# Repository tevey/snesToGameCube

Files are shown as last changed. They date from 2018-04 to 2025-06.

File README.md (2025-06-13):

# SNES to GameCube adapter

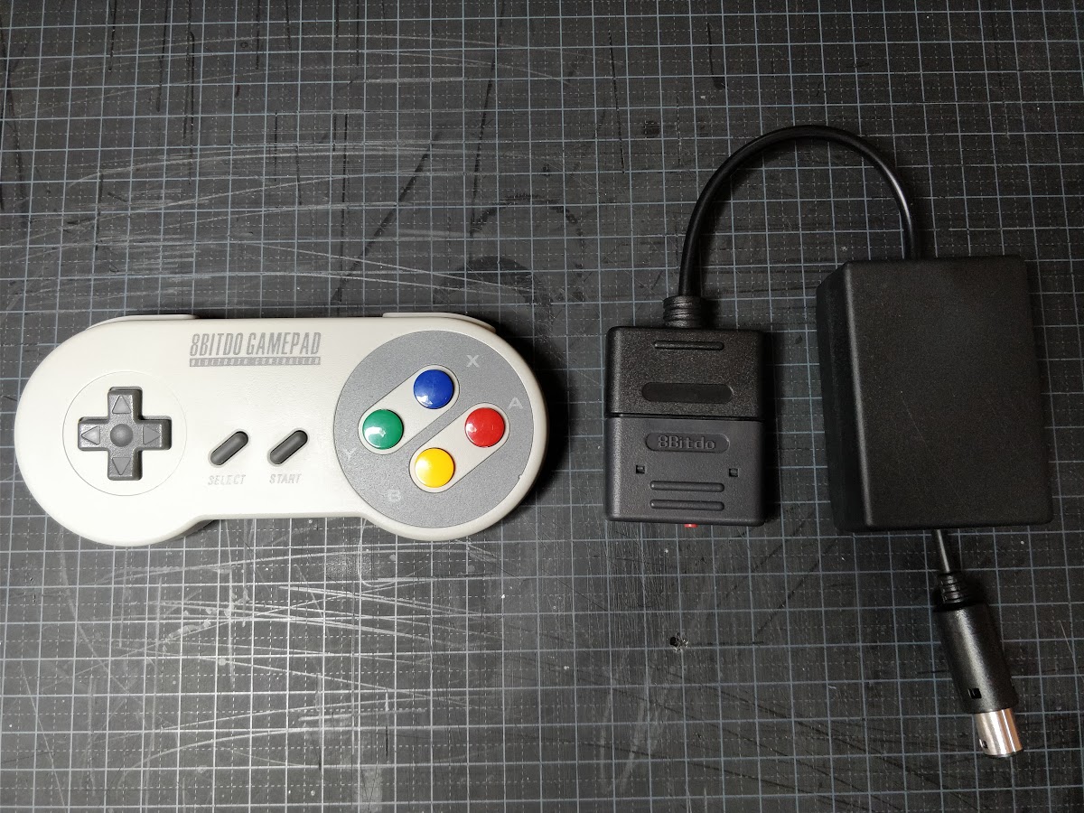
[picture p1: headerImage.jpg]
Image of adapter

Code for building a SNES to GameCube controller adapter.
Also works with the 8Bitdo [Retro Receiver](http://www.8bitdo.com/retro-receiver-snes/)

## Button Mapping

| SNES Button | GameCube Mapping | Notes |
| --- | --- | --- |
| A | A |
| B | B |
| X | X |
| Y | Y |
| Select | Y | Like SNES Hori-pad / for GBA games |
| Start | Start |
| L | L (digital), L (analog: 0/255) | Analog: 255 if pressed, 0 if not |
| R | R (digital), R (analog: 0/255) | Analog: 255 if pressed, 0 if not |
| L+R+Select  | Z |
| D-Pad Left  | D-Pad Left |
| D-Pad Up | D-Pad Up |
| D-Pad Right | D-Pad Right |
| D-Pad Down  | D-Pad Down |

## Software Requirements

- [Arduino IDE](https://www.arduino.cc/en/Main/Software) (tested on 2.3.6)
- [Arduino Nintendo Library](https://github.com/NicoHood/Nintendo) by NicoHood (tested on 1.4.0)

## Hardware

### Parts

- Logic Level Converter 5v <-> 3.3v
- Arduino Pro Mini (5v 16MHz)
- USB -> Serial adapter if your Arduino comes without USB.
- 1kΩ Resistor
- Female SNES controller port (SNES extension cable)
- Male GameCube controller connector (GameCube extension cable)

### Wiring

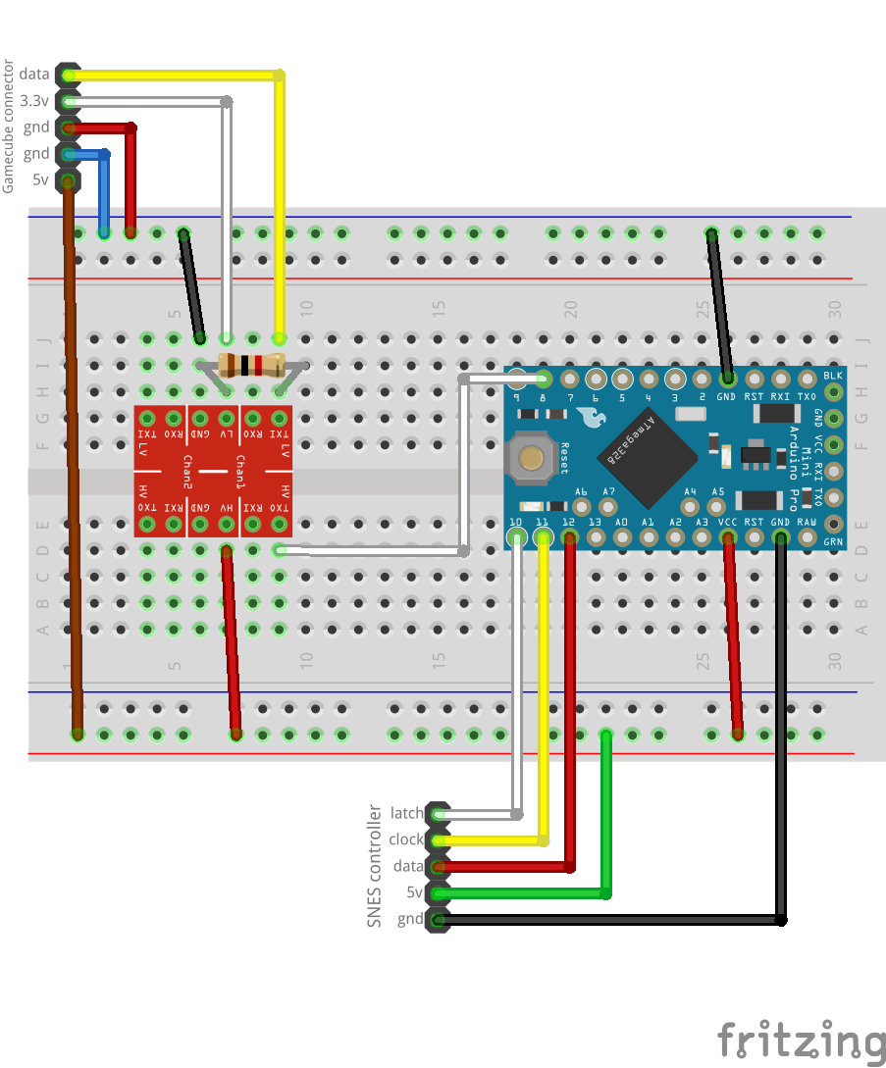
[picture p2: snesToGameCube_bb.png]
Wiring diagram


The colors of the wires in the cables may not match between the original controller and the extension cable, below is the mapping for my cables the colors may be different for you.

#### SNES pinout

| Type  | Original Controller | Extension Cable |
| ----- | --- | --- |
| 5v | white | green |
| clock | yellow | yellow |
| latch | orange | white |
| data  | red | red |
| gnd | brown | black |

#### GameCube Pinout

| Type | Original Controller | Extension Cable |
| ---- | --- | --- |
| gnd  | Black | blue |
| gnd  | white | red |
| gnd  | green | blue |
| data | red | yellow |
| 5v | yellow | brown |
| 3.3v | blue | white |

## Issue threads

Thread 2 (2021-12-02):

Adapter not registering inputs fast enough

MasterJhimmy, 2021-12-02:
Testing this adapter on my Wii I noticed that everything was working alright, but there was a delay. It was very noticeable in fighting games, the adapter would not recognize double taps to run or back off. The problem is that your "write_GC" function is inside of the "if statement" to retrieve data from the SNES controller. Putting the "write_GC" inside the main arduino "loop" mitigate the problem and now everything is working flawless.

Trev154n, 2022-05-04:
@MasterJhimmy can you give me the code you modified? I also noticed a lag using the Wii. thanks.

Trev154n, 2022-05-04:
@MasterJhimmy can you give me the code you modified? I also noticed a lag using the Wii. thanks.

MasterJhimmy, 2022-05-04:
@Trev154n Sure. I've added some features, like when you press the L or R button it registers not only the digital signal, but also the full press of the analog button. Here it is:
[snesToGameCube.txt](https://github.com/tevey/snesToGameCube/files/8627765/snesToGameCube.txt)

Trev154n, 2022-05-04:
@MasterJhimmy thank you very much Bro, I tested it here it's wonderful, now I'm going to do your project, Genesis2CG.you guys are awesome.

Trev154n, 2022-05-04:
@MasterJhimmy thank you very much Bro, I tested it here it's wonderful, now I'm going to do your project, Genesis2CG.you guys are awesome.

Closed 2025-06-13.

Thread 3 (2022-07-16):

Doesn't work with mayflash gamecube adapter

jcgh14, 2022-07-16:
It works great on my wii but I wanted to see if it could work on the switch using the mayflash gamecube adapter. It doesn't seem to register any inputs. Not a deal breaker as I mostly wanted to use this on my wii but it would be nice to use on switch.

SioNisti, 2025-02-06:
im a bit late to this and its not the solution you wanted but:
you can use the GP2040-CE project to make a cheap snes to usb adapter which does work on pc and switch among other consoles.
you can make one for around 10€

tevey, 2025-06-13:
Could be that it's working now with the new code. I have no mayflash adapter so i can't test it.

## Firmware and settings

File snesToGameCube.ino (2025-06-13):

/*
	Code by Viktor René 2018 (@_tEvEy) https://illusionoftime.com
	This code can be found at https://github.com/tevey/ProMicroUSBGamepad
	Uses Arduino Nintendo Library(https://github.com/NicoHood/Nintendo) by NicoHood
  	Updated by Tisse and Viktor 2025 to work better with both Gamecube games, GBI and original Game Boy player.
*/

/*
====SNES PINOUT====
TYPE	| ORIGINAL 	| EXTENSION CABLE
5v		| white 	| green
clock	| yellow 	| yellow
latch	| orange 	| white
data	| red 		| red
gnd		| brown 	| black

====GC PINOUT====
TYPE	| ORIGINAL 	| EXTENSION CABLE
gnd		| Black 	| blue
gnd		| white 	| red
gnd		| green 	| blue
data	| red 		| yellow
5v		| yellow 	| brown
3.3v	| blue 		| white
*/
#include "Nintendo.h"

// SNES button mapping
const int BUTTON_A = 8;
const int BUTTON_B = 0;
const int BUTTON_X = 9;
const int BUTTON_Y = 1;
const int BUTTON_SELECT = 2;
const int BUTTON_START = 3;
const int BUTTON_R = 11;
const int BUTTON_L = 10;
const int DPAD_UP = 4;
const int DPAD_DOWN = 5;
const int DPAD_LEFT = 6;
const int DPAD_RIGHT = 7;

// SNES pins
const int SNES_DATA_CLOCK_PIN = 11;
const int SNES_DATA_LATCH_PIN = 10;
const int SNES_DATA_SERIAL_PIN = 12;

// Array holding SNES buttons states
int buttons[16];

// Assign Polling variables
long pollInterval;
long nextPoll;

int GC_DATA_PIN = 8;
// This makes the controller bidirection data line on pin number8
CGamecubeConsole GamecubeConsole(GC_DATA_PIN); // Defines a "Gamecube Console" sending data to the console on pin 8
Gamecube_Data_t d = defaultGamecubeData;	   // Structure for data to be sent to console

// This is needed but you don't need a controller on pin 7
CGamecubeController GamecubeController1(7);

void setup()
{
	// Set SNES_DATA_CLOCK_PIN normally HIGH
	pinMode(SNES_DATA_CLOCK_PIN, OUTPUT);
	digitalWrite(SNES_DATA_CLOCK_PIN, HIGH);

	// Set SNES_DATA_LATCH_PIN normally LOW
	pinMode(SNES_DATA_LATCH_PIN, OUTPUT);
	digitalWrite(SNES_DATA_LATCH_PIN, LOW);

	// Set SNES_DATA_SERIAL_PIN normally HIGH
	pinMode(SNES_DATA_SERIAL_PIN, OUTPUT);
	digitalWrite(SNES_DATA_SERIAL_PIN, HIGH);
	pinMode(SNES_DATA_SERIAL_PIN, INPUT);

	// Initiate buttons-array
	buttons[0] = 0;
	buttons[1] = 0;
	buttons[2] = 0;
	buttons[3] = 0;
	buttons[4] = 0;
	buttons[5] = 0;
	buttons[6] = 0;
	buttons[7] = 0;
	buttons[8] = 0;
	buttons[9] = 0;
	buttons[10] = 0;
	buttons[11] = 0;
	// Buttons [12 - 15] are not being used, but we initiate them anyway.
	buttons[12] = 0;
	buttons[13] = 0;
	buttons[14] = 0;
	buttons[15] = 0;


	//Initiate Poll-interval varaiables
	pollInterval = 6667; // microseconds for 150Hz
	nextPoll = micros(); // set up nextPoll to be done directly

	// This is needed to run the code.
	GamecubeController1.read();

	//Send a first response to gamecube directly
  updateGCReport();
  while (!GamecubeConsole.write(d)){}
}


void loop()
{
	if (micros() >= nextPoll)
	{
		readSNES();		
		updateGCReport(); 
		nextPoll = micros() + pollInterval;
	}
	// Always respond to GameCube as fast as possible
	while (!GamecubeConsole.write(d)){}
}

void readSNES()
{
	// Latch for 12us
	digitalWrite(SNES_DATA_LATCH_PIN, HIGH);
	delayMicroseconds(12);
	digitalWrite(SNES_DATA_LATCH_PIN, LOW);
	delayMicroseconds(6);

	// Retrieve button presses from shift register by pulsing the clock LOW, reading the data, then setting the clock HIGH.
	for (int i = 0; i < 16; i++)
	{
		digitalWrite(SNES_DATA_CLOCK_PIN, LOW);
		delayMicroseconds(6);
		buttons[i] = !digitalRead(SNES_DATA_SERIAL_PIN);
		digitalWrite(SNES_DATA_CLOCK_PIN, HIGH);
		delayMicroseconds(6);
	}
}

void updateGCReport()
{
	// Sends the complied data to console when console polls for the input
	d.report.a = buttons[BUTTON_A];
	d.report.b = buttons[BUTTON_B];
	d.report.x = buttons[BUTTON_X];
	d.report.y = buttons[BUTTON_Y];
	// Map Select-button to Y since this is how the SNES Hori-pad and the GBA-games works
	if (buttons[BUTTON_Y] == 0)
	{
		d.report.y = buttons[BUTTON_SELECT];
	}
	d.report.start = buttons[BUTTON_START];
	d.report.r = buttons[BUTTON_R];
	d.report.l = buttons[BUTTON_L];
	// L and R analog require values from 0-255, so send 255 or 0 if button is pressed or unpressed
	d.report.right = buttons[BUTTON_R] * 255;
	d.report.left = buttons[BUTTON_L] * 255;
	// Press L+R+Select for Z
	if (buttons[BUTTON_SELECT] + buttons[BUTTON_R] + buttons[BUTTON_L] == 3)
	{
		d.report.y = 0;
		d.report.r = 0;
		d.report.l = 0;
		d.report.right = 0;
		d.report.left = 0;
		d.report.z = 1;
	}
	else
	{
		d.report.z = 0;
	}

	d.report.dleft = buttons[DPAD_LEFT];
	d.report.dup = buttons[DPAD_UP];
	d.report.dright = buttons[DPAD_RIGHT];
	d.report.ddown = buttons[DPAD_DOWN];
}
